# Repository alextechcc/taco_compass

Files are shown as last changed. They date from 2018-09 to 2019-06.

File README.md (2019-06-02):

# Taco Compass
Using a Raspberry Pi, a custom connector Pi hat, a USB GPS and a 9-dof IMU, and scraped google places API data, I have made a plush taco that acts as a compass pointing at the nearest taco restaurant. 

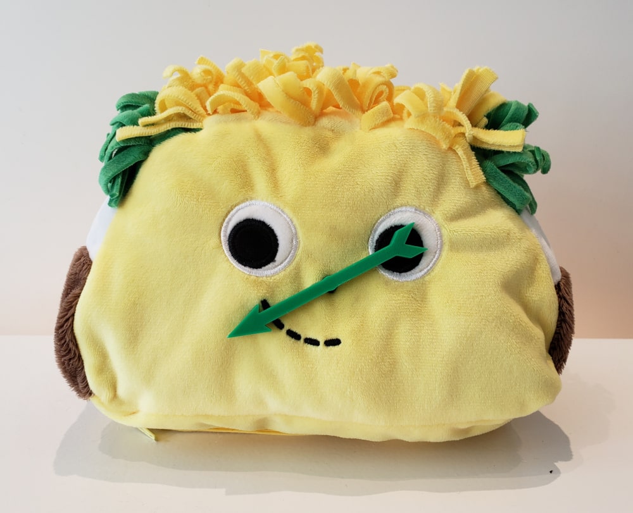
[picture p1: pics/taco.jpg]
Taco

Schematic
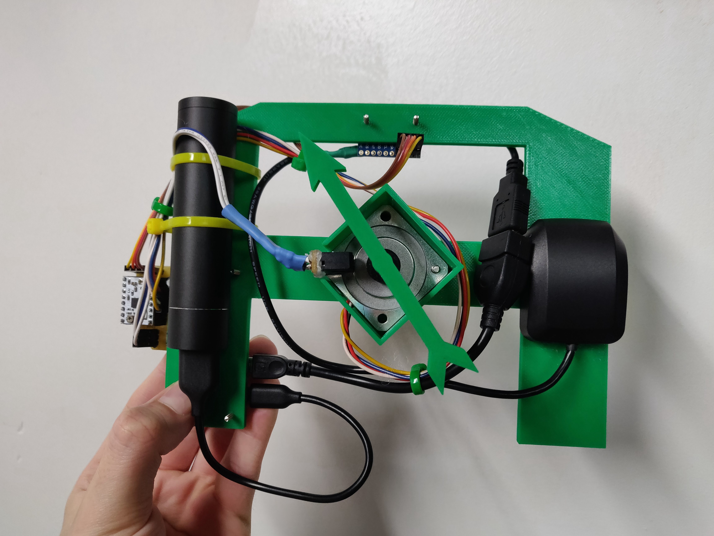
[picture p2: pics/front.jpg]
Front

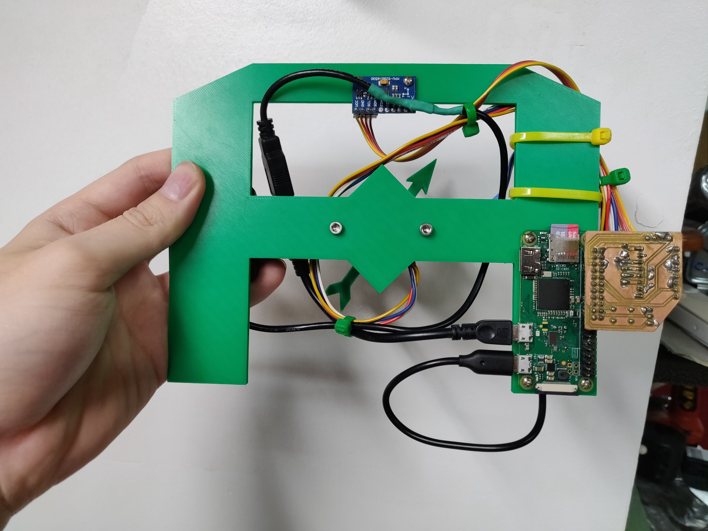
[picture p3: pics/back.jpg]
Back


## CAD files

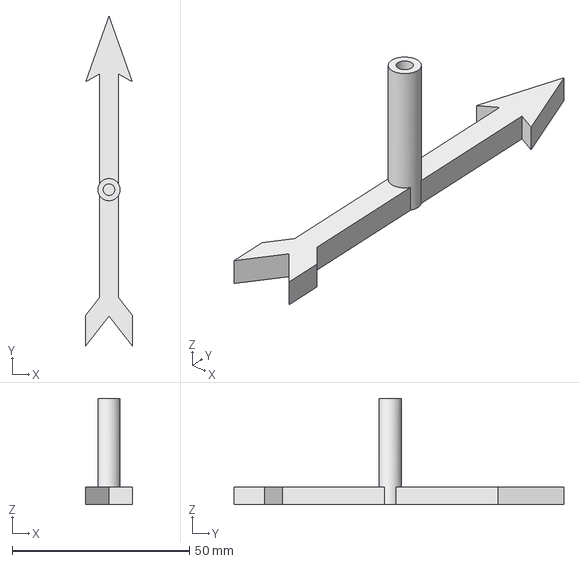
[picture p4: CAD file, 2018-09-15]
freecad_models/freecad_models.fcstd
13.2 x 93.1 x 30.0 mm

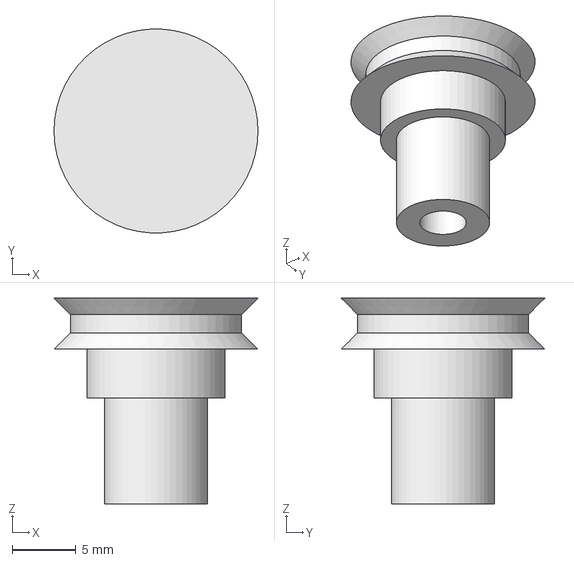
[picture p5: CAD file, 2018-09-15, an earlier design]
freecad_models_old/stepper_assembly.FCStd
16.0 x 16.0 x 16.1 mm

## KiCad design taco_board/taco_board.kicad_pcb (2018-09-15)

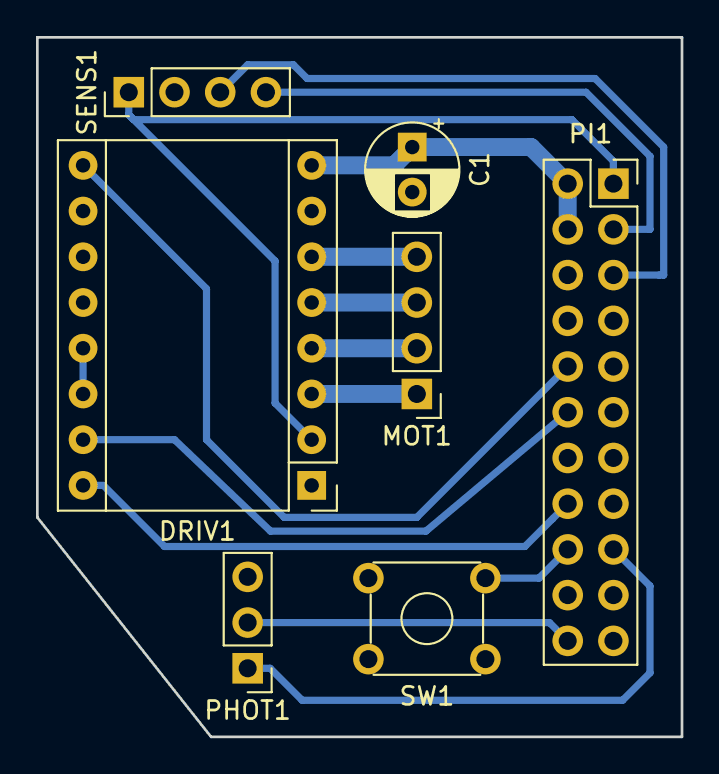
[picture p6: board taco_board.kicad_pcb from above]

Board: 2 copper layers, 35.8 x 38.9 mm, 7 parts (0 on the bottom side), 16 nets.

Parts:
C1: CP1; CP_Radial_D5.0mm_P2.50mm
DRIV1: Pololu_Breakout_A4988; Pololu_Breakout-16_15.2x20.3mm
MOT1: Stepper_Header; PinHeader_1x04_P2.54mm_Vertical
PHOT1: Photo_Interrupter; PinHeader_1x03_P2.54mm_Vertical
PI1: PI_PartialHeader; PinSocket_2x11_P2.54mm_Vertical
SENS1: MPU_9250_Breakout; PinHeader_1x04_P2.54mm_Vertical
SW1: SW_DPST; SW_TH_Tactile_Omron_B3F-10xx

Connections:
+5V: C1.1, DRIV1.8, PI1.2, PI1.4
/3v3_1: DRIV1.2, PI1.1, SENS1.1
/3v3_2: PHOT1.1, PI1.17
/MOT_DIR: DRIV1.16, PI1.16
/MOT_STEP: DRIV1.15, PI1.12
/SCL: PI1.5, SENS1.3
/SDA: PI1.3, SENS1.4
/~BUT: PI1.18, SW1.3
/~MOT_ENABLE: DRIV1.9, PI1.10
/~PHOTO_SIG: PHOT1.2, PI1.22
GND: C1.2, DRIV1.1, DRIV1.7, DRIV1.10, DRIV1.11, DRIV1.12, PHOT1.3, PI1.6, PI1.9, PI1.20, SENS1.2, SW1.4
unnamed: DRIV1.3, MOT1.1
unnamed: DRIV1.4, MOT1.2
unnamed: DRIV1.5, MOT1.3
unnamed: DRIV1.6, MOT1.4
unnamed: DRIV1.13, DRIV1.14

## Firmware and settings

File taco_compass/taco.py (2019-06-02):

#!/usr/bin/env python3

import time
from multiprocessing import Value
from utils import read_restaurants, get_delta
from stepper_proc import Stepper_Process
from imu_proc import IMU_Process
from gps_proc import GPS_Process
import math
import sys
import pickle
import socket

def main():
    if len(sys.argv) > 1:
        s = socket.socket(socket.AF_INET, socket.SOCK_STREAM)
        s.connect((sys.argv[1], 15975))

    restaurants = read_restaurants()

    yaw = Value('d')
    imu_proc = IMU_Process(yaw)
    imu_proc.start()

    # Stepper is Red Blue White Yellow from top to bottom (towards knob) Dir = LOW means clockwise
    target_angle = Value('d')
    stepper_proc = Stepper_Process(target_angle, 15, 18, 23, 25, 200)
    stepper_proc.start()

    lat, lon = Value('d'), Value('d')
    gps_proc = GPS_Process(lat, lon)
    gps_proc.start()

    print_state = False
    while True:
        bearing = yaw.value
        delta, closest, dist = get_delta(bearing, restaurants, (lat.value, lon.value))
        target_angle.value = delta

        if math.floor(time.time() % 2) != print_state:
            data = (closest.name, dist, bearing, delta, closest.lat, closest.lon, lat.value, lon.value)

            if len(sys.argv) > 1:
                s.send(pickle.dumps(data))
            else:
                print('Closest: {}, Dist: {:.2f}\n\tBearing: {:.0f}, Delta: {:.0f}\n\tClosest: {},{}\n\tLoc: {},{}'
                                        .format(*data))

            print_state = not print_state
        time.sleep(0.005)

if __name__ == '__main__':
    main()

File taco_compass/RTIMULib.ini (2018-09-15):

# #####################################################################
# 
# RTIMULib settings file

# General settings
# 

# IMU type - 
#   0 = Auto discover
#   1 = Null (used when data is provided from a remote IMU
#   2 = InvenSense MPU-9150
#   3 = STM L3GD20H + LSM303D
#   4 = STM L3GD20 + LSM303DLHC
#   5 = STM LSM9DS0
#   6 = STM LSM9DS1
#   7 = InvenSense MPU-9250
#   8 = STM L3GD20H + LSM303DLHC
#   9 = Bosch BMX055
#   10 = Bosch BNX055
IMUType=7

# 
# Fusion type type - 
#   0 - Null. Use if only sensor data required without fusion
#   1 - Kalman STATE4
#   2 - RTQF
FusionType=2

# 
# Is bus I2C: 'true' for I2C, 'false' for SPI
BusIsI2C=true

# 
# I2C Bus (between 0 and 7) 
I2CBus=1

# 
# SPI Bus (between 0 and 7) 
SPIBus=0

# 
# SPI select (between 0 and 1) 
SPISelect=0

# 
# SPI Speed in Hz
SPISpeed=500000

# 
# I2C slave address (filled in automatically by auto discover) 
I2CSlaveAddress=104

# 
# IMU axis rotation - see RTIMU.h for details
AxisRotation=0

# Pressure sensor type - 
#   0 = Auto discover
#   1 = Null (no hardware or don't use)
#   2 = BMP180
#   3 = LPS25H
#   4 = MS5611
#   5 = MS5637
PressureType=0

# 
# I2C pressure sensor address (filled in automatically by auto discover) 
I2CPressureAddress=0

# Humidity sensor type - 
#   0 = Auto discover
#   1 = Null (no hardware or don't use)
#   2 = HTS221
#   3 = HTU21D
HumidityType=0

# 
# I2C humidity sensor address (filled in automatically by auto discover) 
I2CHumidityAddress=0

# #####################################################################
# 

# Compass calibration settings
CompassCalValid=true
CompassCalMinX=31.375443
CompassCalMinY=-49.904987
CompassCalMinZ=16.274164
CompassCalMaxX=145.648224
CompassCalMaxY=43.647343
CompassCalMaxZ=130.436218

# #####################################################################
# 

# Compass adjustment settings
# Compass declination is in radians and is subtracted from calculated heading
compassAdjDeclination=0.000000

# #####################################################################
# 

# Compass ellipsoid calibration
compassCalEllipsoidValid=true
compassCalOffsetX=-4.286066
compassCalOffsetY=6.279439
compassCalOffsetZ=7.381172
compassCalCorr11=0.899085
compassCalCorr12=-0.032253
compassCalCorr13=0.023680
compassCalCorr21=-0.032253
compassCalCorr22=0.737412
compassCalCorr23=0.017681
compassCalCorr31=0.023680
compassCalCorr32=0.017681
compassCalCorr33=0.994038

# #####################################################################
# 

# Accel calibration
AccelCalValid=true
AccelCalMinX=-0.992108
AccelCalMinY=-0.979329
AccelCalMinZ=-1.042348
AccelCalMaxX=1.003573
AccelCalMaxY=1.026234
AccelCalMaxZ=1.045300

# #####################################################################
# 

# Saved gyro bias data
GyroBiasValid=true
GyroBiasX=-0.055503
GyroBiasY=-0.063598
GyroBiasZ=-0.029039

# #####################################################################
# 
# MPU-9150 settings
# 

# Gyro sample rate (between 5Hz and 1000Hz) 
MPU9150GyroAccelSampleRate=50

# 
# Compass sample rate (between 1Hz and 100Hz) 
MPU9150CompassSampleRate=25

# 
# Gyro/accel low pass filter - 
#   0 - gyro: 256Hz, accel: 260Hz
#   1 - gyro: 188Hz, accel: 184Hz
#   2 - gyro: 98Hz, accel: 98Hz
#   3 - gyro: 42Hz, accel: 44Hz
#   4 - gyro: 20Hz, accel: 21Hz
#   5 - gyro: 10Hz, accel: 10Hz
#   6 - gyro: 5Hz, accel: 5Hz
MPU9150GyroAccelLpf=4

# 
# Gyro full scale range - 
#   0  - +/- 250 degress per second
#   8  - +/- 500 degress per second
#   16 - +/- 1000 degress per second
#   24 - +/- 2000 degress per second
MPU9150GyroFSR=16

# 
# Accel full scale range - 
#   0  - +/- 2g
#   8  - +/- 4g
#   16 - +/- 8g
#   24 - +/- 16g
MPU9150AccelFSR=16

# #####################################################################
# 
# MPU-9250 settings
# 

# Gyro sample rate (between 5Hz and 1000Hz plus 8000Hz and 32000Hz) 
MPU9250GyroAccelSampleRate=80

# 
# Compass sample rate (between 1Hz and 100Hz) 
MPU9250CompassSampleRate=40

# 
# Gyro low pass filter - 
#   0x11 - 8800Hz, 0.64mS delay
#   0x10 - 3600Hz, 0.11mS delay
#   0x00 - 250Hz, 0.97mS delay
#   0x01 - 184Hz, 2.9mS delay
#   0x02 - 92Hz, 3.9mS delay
#   0x03 - 41Hz, 5.9mS delay
#   0x04 - 20Hz, 9.9mS delay
#   0x05 - 10Hz, 17.85mS delay
#   0x06 - 5Hz, 33.48mS delay
MPU9250GyroLpf=3

# 
# Accel low pass filter - 
#   0x08 - 1130Hz, 0.75mS delay
#   0x00 - 460Hz, 1.94mS delay
#   0x01 - 184Hz, 5.80mS delay
#   0x02 - 92Hz, 7.80mS delay
#   0x03 - 41Hz, 11.80mS delay
#   0x04 - 20Hz, 19.80mS delay
#   0x05 - 10Hz, 35.70mS delay
#   0x06 - 5Hz, 66.96mS delay
MPU9250AccelLpf=3

# 
# Gyro full scale range - 
#   0  - +/- 250 degress per second
#   8  - +/- 500 degress per second
#   16 - +/- 1000 degress per second
#   24 - +/- 2000 degress per second
MPU9250GyroFSR=16

# 
# Accel full scale range - 
#   0  - +/- 2g
#   8  - +/- 4g
#   16 - +/- 8g
#   24 - +/- 16g
MPU9250AccelFSR=16
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

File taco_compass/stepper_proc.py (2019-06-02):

#!/usr/bin/env python3

import time
import RPi.GPIO as GPIO
import atexit
from collections import namedtuple
from multiprocessing import Process

class Stepper_Process(Process):
    stepper_pins = namedtuple('stepper_pins',
                              ['enable', 'step', 'dir', 'sens'])
    def __init__(self, target_angle, enable_pin, step_pin, dir_pin, sens_pin, steps_per_rev):
        super().__init__()
        self.daemon = True
        self.target_angle = target_angle
        self.pins = Stepper_Process.stepper_pins(enable_pin, step_pin, dir_pin,
                                                 sens_pin)
        self.pos_angle = 0
        self.steps_per_rev = steps_per_rev
        self.step_angle = 360 / self.steps_per_rev
        self.rate = 0.005
        self.idle_ticks = 10
        self.idle_counter = 0
        self.init_gpio()
        self.CAL_RETRY_COUNT = 4
        print('Steps per rev: {}, Step angle: {}'.format(self.steps_per_rev, self.step_angle))
        self.calibrate()
        atexit.register(self.cleanup)

    def run(self):
        while True:
            if abs(self.target_angle.value - self.pos_angle) > self.step_angle * 1.5:
                GPIO.output(self.pins.enable, False)
                direction = self.get_target_direction()
                self.step(direction)
                self.idle_counter = 0
            elif self.idle_counter < self.idle_ticks:
                self.idle_counter += 1
                time.sleep(self.rate * 2)
            else:
                GPIO.output(self.pins.enable, True)
                time.sleep(self.rate * 2)

    def sens_stable(self, samples=5):
        on_count = 0
        for i in range(samples):
            if GPIO.input(self.pins.sens):
                on_count += 1
            time.sleep(0.001)
        return on_count > 0

    def calibrate(self):
        GPIO.output(self.pins.enable, False)
        # If already under sensor, move away first
        if self.sens_stable():
            for i in range(20):
                self.step(False)
        while not self.sens_stable():
            self.step(True)

        GPIO.output(self.pins.enable, True)
        self.pos_angle = 0
        print('Motor Calibrated')


    def get_target_direction(self):
        # If we're more than 180 degrees off from the target, go the opposite way to get to it
        invert = abs(self.target_angle.value - self.pos_angle) > 180
        direction = self.target_angle.value - self.pos_angle > 1
        return direction != invert

    def step(self, clockwise):
        GPIO.output(self.pins.dir, clockwise)
        time.sleep(self.rate)
        GPIO.output(self.pins.step, True)
        time.sleep(self.rate)
        GPIO.output(self.pins.step, False)
        if clockwise:
            self.pos_angle = (self.pos_angle + self.step_angle) % 360
        else:
            self.pos_angle = (self.pos_angle - self.step_angle) % 360

    def init_gpio(self):
        GPIO.setwarnings(False)
        GPIO.setmode(GPIO.BCM)
        GPIO.setup(self.pins.enable, GPIO.OUT)
        GPIO.setup(self.pins.step, GPIO.OUT)
        GPIO.setup(self.pins.dir, GPIO.OUT)
        GPIO.setup(self.pins.sens, GPIO.IN, pull_up_down=GPIO.PUD_UP)
        self.disable_motors()

    def cleanup(self):
        self.disable_motors()
        #GPIO.cleanup()

    def disable_motors(self):
        GPIO.output(self.pins.step, False)
        GPIO.output(self.pins.dir, False)
        GPIO.output(self.pins.enable, True)
